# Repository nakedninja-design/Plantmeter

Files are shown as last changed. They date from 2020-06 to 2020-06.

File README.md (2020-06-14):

# Plant-Meter
Wireless Plant Meter (ESP8266 + ATTiny85)

The Plantmeter is a device that monitors the soil moisture levels of your plants.
It uses authenticated HTTP POST command over Wifi to communicate with a plantmeter hub that gathers all the data and notifies you when a plant needs watering.

Works with any webserver, home automation system  or other device that can process HTTP POST commands.

Works right out of the box in combination with our plantmeter hub.
Has its own webinterface to configure the ID, network settings and sleep time.

The plantmeter is a rechargeable, battery powered, device that can operate for 6 months on 1 charge.
Comes with STL design files for 3d printed enclosure.

You can buy the plantmeter on my website http://nakedninja.cc

Specifications:

Microcontroller: ESP8266 (ESP12)
- Flash Memory: 4MB
- RAM: 36kB
- Clock Speed: 80MHz
- Operating Voltage: 3.3V
Microcontroller: ATtiny85
- Flash Memory: 8kB
- RAM: 512B
- Clock Speed: 1MHz
- Operating Voltage: 2.7 to 5.5V
Power Supply Voltage: 5 Volt
Operating Current:
- Standby mode: 16~ 25uA
- Active mode: 50 ~ 80mA
Battery: Li-ion 3.7 Volt
Battery Connector: Solder Pads
Charger Module: TP4056

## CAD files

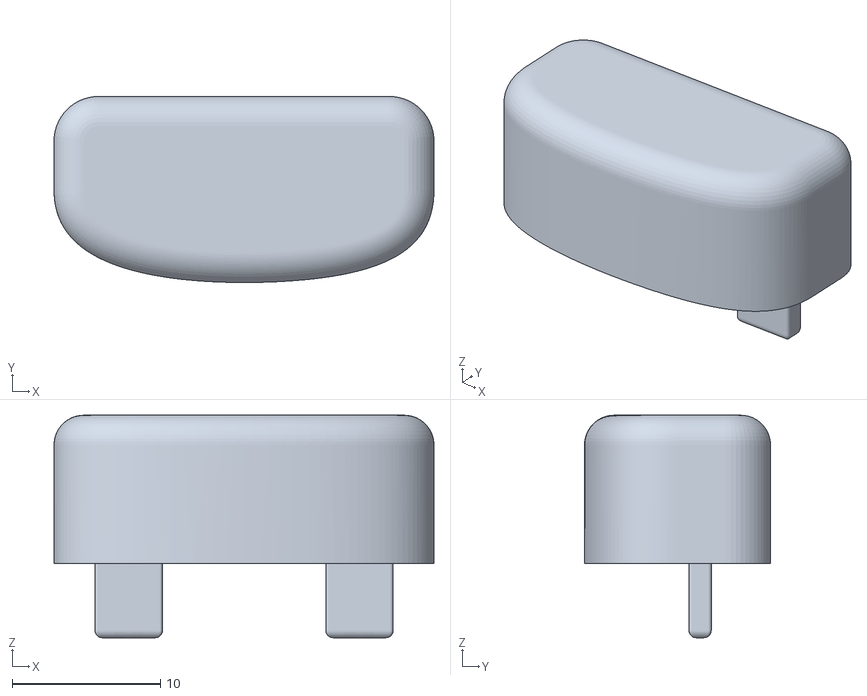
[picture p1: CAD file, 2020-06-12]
STL files Shorty/Shorty Enclosure Top.stl
25.6 x 12.5 x 15.0

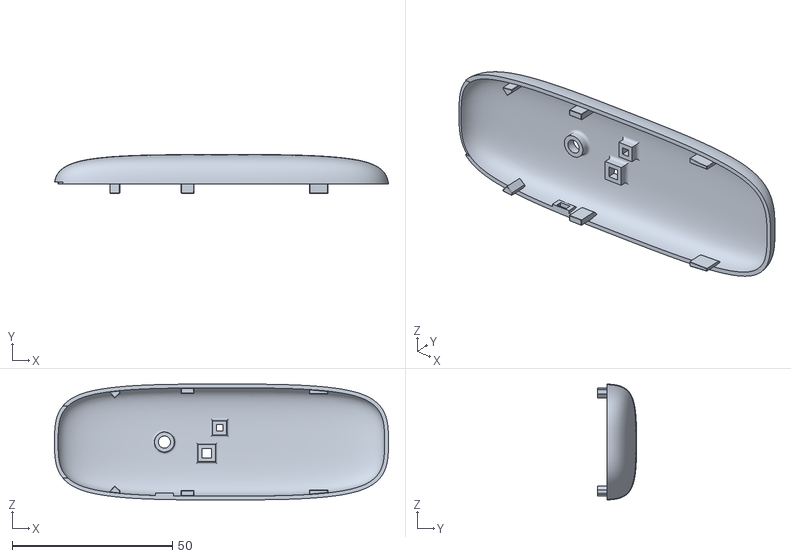
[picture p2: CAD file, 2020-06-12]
STL files TallBoy/TallBoy Enclosure Top.stl
104.2 x 12.2 x 36.2

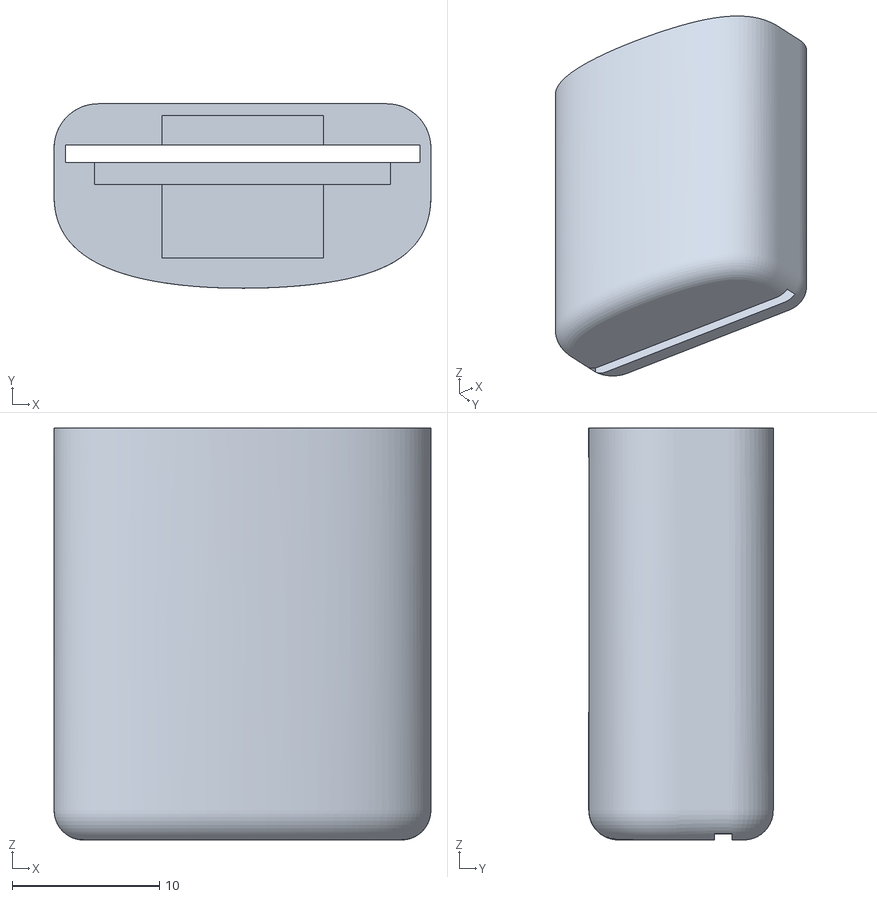
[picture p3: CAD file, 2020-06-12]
STL files Shorty/Shorty Enclosure Bottom.stl
25.6 x 12.5 x 28.0

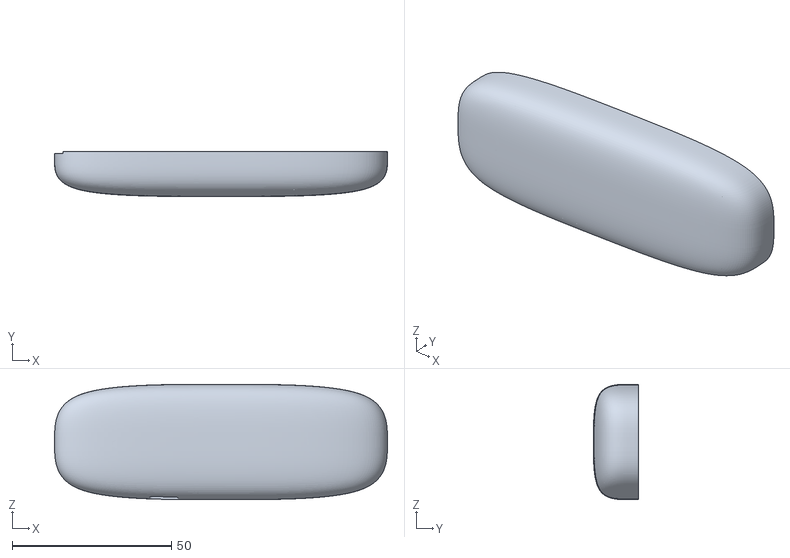
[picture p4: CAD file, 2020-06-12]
STL files TallBoy/TallBoy Enclosure Bottom.stl
104.4 x 14.2 x 36.2

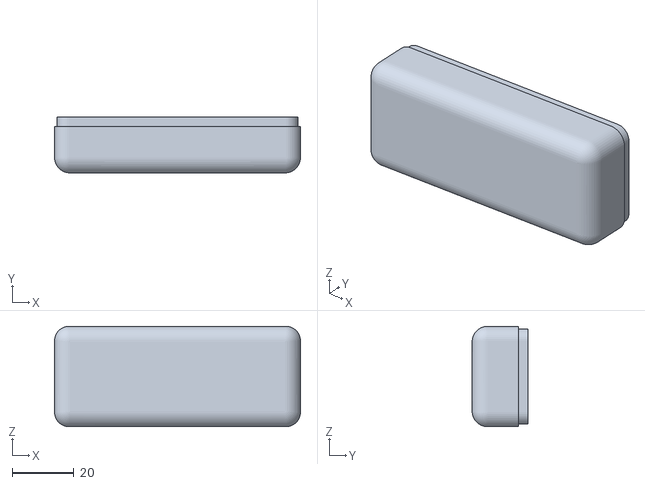
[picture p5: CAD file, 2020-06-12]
STL files Shorty/Plantmeter Enclosure Bottom.stl
79.4 x 18.0 x 32.4

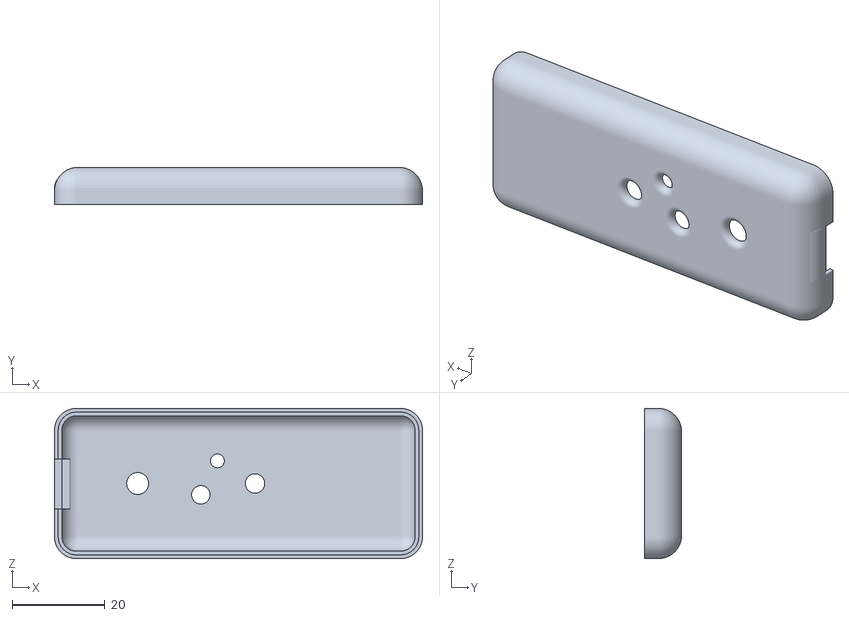
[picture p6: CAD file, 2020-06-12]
STL files Shorty/Plantmeter Enclosure Top.stl
79.4 x 8.00 x 32.4

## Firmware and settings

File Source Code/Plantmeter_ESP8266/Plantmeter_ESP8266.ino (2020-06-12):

/*
 * Web Interfacing Program for Plantmeter ESP
 * 
 * Company:    Naked Ninja (c) 2020
 * Website:    https://nakedninja.cc
 * Author(s):  Caner Erdem & Harm Verbeek
 * 
 * Pins that are connected on the PCB are:
 * GPIO4    -(I/O)->  SDA for I2C connection to the HTU21 & gy-49.
 * GPIO5    -(I/O)->  SCL for I2C connection to the HTU21 & gy-49.
 * GPIO12   -(TX)->   Serial communication with the ATtiny85
 * GPIO13   -(RX)->   Serial communication with the ATtiny85
 * GPIO14   -(O)->    RGB LED
 * ADC      -(I)->    Moisture sensor data input
 * 
 * Arduino IDE version 1.8.9
 * 
 * ESP8266 upload settings:
 *  Board:              Generic ESP8266 module
 *  Upload speed:       921600
 *  CPU freqyency:      80 MHz
 *  Flash frequency:    40 MHz
 *  Flash mode:         DOUT (compatible)
 *  Flash size:         4M (FS:1M)
 *  Crystal frequency:  26MHz
 *  Reset method:       nodemcu
 *  Debug port:         Disabled
 *  Debug level:        None
 *  IwIP variant:       v2 Lower Memory
 *  VTables:            Flash
 *  Exceptions:         Disabled
 *  Builtin LED:        2
 *  Erase flash:        All flash contents
 *  Espressif FW:       nonos-sdk 2.2.1 (legacy)
 *  SSL support:        All SSL ciphers (most compatible)
 * 
 * Programmer: AVRISP mkII
 * 
 * Component datasheets & usefull links:
 *  - GY-49: https://www.digchip.com/datasheets/parts/datasheet/280/MAX44009-pdf.php
 *  - HTU21: http://www.farnell.com/datasheets/1780639.pdf
 *  - Cap. Moisture sensor: https://wiki.dfrobot.com/Capacitive_Soil_Moisture_Sensor_SKU_SEN0193
 * 
 */

// Libraries
#include <ArduinoJson.h>
#include <FS.h>
#include <Wire.h>
#include "SparkFunHTU21D.h"
#include <ESP8266WiFi.h>          // https://github.com/esp8266/Arduino
#include <ESP8266WebServer.h>
#include <WiFiManager.h>          // https://github.com/tzapu/WiFiManager
#include <ESP8266HTTPClient.h>
#include <SoftwareSerial.h>
#include <Adafruit_NeoPixel.h>
#include <Ticker.h>

// Create timer
Ticker ticker;

// Code version
#define VERSION     "v1.27"

// Enable / Disable serial debug output
#define DEBUG true // flag to turn on/off debugging
#define USE_SERIAL if(DEBUG)Serial 

// Pin configuration
#define RGB_LED_PIN     14  // Connected RGB LED

// RGB settings & control modes
#define RGB_BRIGHTNESS    64          // Between 0 and 255
#define BLINK_DELAY       250         // Time in ms
#define LED_OFF           0,0,0       // OFF
#define LED_RED           255,0,0     // Red
#define LED_GREEN         0,255,0     // Green
#define LED_BLUE          0,0,255     // Blue
#define LED_YELLOW        255,255,0   // Yellow
#define LED_PURPLE        128,0,255   // Purple
#define LED_ORANGE        255,128,0   // Orange
#define LED_PINK          255,0,255   // Pink
#define LED_WHITE         255,255,255 // White

/* RGB LED status messages
 *    <COLOR>, <NUMBER>
 * <COLOR> is the color that will be visualized on the RGB LED
 * <NUMBER> is the amount of times the RGB will blink the given color
 * If <NUMBER> is set to -1, it will toggle the RGB LED to the given color
*/
#define BLINK_SAVE_CONFIG_SUCCESS       LED_GREEN, 2
#define BLINK_SAVE_CONFIG_ERROR         LED_RED, 2
#define BLINK_HTTP_RCV_OK               LED_GREEN, 2
#define BLINK_HTTP_RCV_ERROR            LED_RED, 2
#define BLINK_SSID_MISSING              LED_RED, 2
#define BLINK_WIFI_MAX_RETRIES          LED_RED, 2
#define TOGGLE_PORTAL                   LED_YELLOW, -1
#define TOGGLE_MOISTURE_MEASURE         LED_WHITE, -1
#define BLINK_MOISTURE_MEASURE_TIMEOUT  LED_RED, 2
#define BLINK_MOISTURE_MEASURE_FAIL     LED_RED, 2
#define BLINK_MODE_ERROR                LED_RED, 2
#define BLINK_SERIAL_NO_RESPONSE        LED_RED, 2
#define BLINK_MODE_CHARGE               LED_PURPLE, 5

// Modes
#define MODE_PORTAL             0x01 
#define MODE_SET_MOISTURE       0x02 
#define MODE_TEST               0x03 
#define WATCHDOG_TIMER          0x04
#define MODE_START_UP           0x05 
#define MODE_CHARGE             0x06
#define MODE_PRESSED            0x07
#define MODE_ERROR              0x99

// Serial communication codes
#define COMMUNICATION_ID_1      0xAA  // Header code 1 
#define COMMUNICATION_ID_2      0x55  // Header code 2
#define ESP_DONE                0xB1  // HEX code for shutdown command
#define REQUEST_MODE            0xA1  // HEX code for start up mode request
#define REQUEST_RESET           0xA2  // HEX code for ATtiny85 reset request
#define RCVD_ERROR              0xAF  // HEX code for Error message
#define RCVD_SUCCESS            0xFE  // HEX code for success message

// Delays, timers & retries
#define SERIAL_TIMEOUT          3000  // Max serial communication time per attempt
#define MOISTURE_TIMEOUT        20000 // Max time to put device in soil and press the function button
#define SERIAL_ATTEMPTS         5     // Amount of serial communication attempts before timeout
#define MAX_WIFI_RETRIES        12    // Amount of Wifi communication attempts before timeout
#define CMP_OFFSET              50    // Value for dry and wet offset check

// Default values
#define DEF_URL                 "http://%s.local/plantmeter"  // $s will be replaced with ssid
#define DEF_ID                  "Plantmeter"                  // Device ID
#define DEF_AUTH_USER           "user"                        // Basic Authentication User
#define DEF_AUTH_PASSWORD       "user"                        // Basic Authentication Password
#define DEF_SOIL_MOISTURE_DRY   600                           // Default dry level
#define DEF_SOIL_MOISTURE_WET   "250"                         // Default wet level
#define DEF_WAKE_TIME           300                           // Seconds the ATtiny85 will be awake if no ESP_DONE is received
#define DEF_SLEEP_TIME          "600"                         // Seconds the ATtiny85 will sleep

// Sensor settings
#define GY49_ADDR 0x4A  // Light sensor addres
HTU21D HTU21;           // HTU21 object creation

// Create softwareserial connection
SoftwareSerial mySerial(13, 12);  // RX, TX

// Create RGB LED class
Adafruit_NeoPixel pixel(1, RGB_LED_PIN, NEO_GRB + NEO_KHZ800);

// Allocate a JsonDocument
StaticJsonDocument<200> json;

// Global value's
char my_id[50]                = "";
char my_auth_password[10]     = "";
char my_soil_moisture_wet[10] = "";
char my_sleep_time[10]        = "";

// flags 
bool shouldSaveConfig = false;
bool flag_color_toggle = false;

// Mode
byte mode_state = 0;

// Call for timer interrupt
void tick() {
  controlRGB(TOGGLE_PORTAL);
}

//callback notifying us of the need to save config
void saveConfigCallback () {
  USE_SERIAL.println("Should save config");
  shouldSaveConfig = true;
}

void loadConfig () { 
    if (SPIFFS.begin()) {
      USE_SERIAL.println("Mounted file system");    
      File configFile = SPIFFS.open("/config.json", "r");
      
      if (configFile) {
        USE_SERIAL.println("Reading config file");
        // Deserialize the JSON document
        DeserializationError error = deserializeJson(json, configFile);
        if (error) {
          USE_SERIAL.println("Failed to load json config");
        } 
        else {    
          USE_SERIAL.println("\nparsed json");

          strcpy(my_id, json["id"]);
          strcpy(my_auth_password, json["auth_password"]);
          strcpy(my_soil_moisture_wet, json["soil_moisture_wet"]);
          strcpy(my_sleep_time, json["sleep_time"]);

          USE_SERIAL.println(my_id);
          USE_SERIAL.println(my_auth_password);
          USE_SERIAL.println(my_soil_moisture_wet);
          USE_SERIAL.println(my_sleep_time);
        }
        
        configFile.close();
      }
      else { // No config file found
        // create config file with default values
        USE_SERIAL.println("Creating config file with default values");
    
        strcpy(my_id, DEF_ID);
        strcpy(my_auth_password, DEF_AUTH_PASSWORD);
        strcpy(my_soil_moisture_wet, DEF_SOIL_MOISTURE_WET);
        strcpy(my_sleep_time, DEF_SLEEP_TIME);

        USE_SERIAL.println("Saving config");

        json["id"] = my_id;
        json["auth_password"] = my_auth_password;
        json["soil_moisture_wet"] = my_soil_moisture_wet;
        json["sleep_time"] = my_sleep_time;
    
        File configFile = SPIFFS.open("/config.json", "w+");
        if (!configFile) {
          USE_SERIAL.println("Failed to open config file for writing");
        } 
        else {
          // Serialize JSON to file
          if (serializeJson(json, configFile) == 0) {
            USE_SERIAL.println(F("Failed to write to file"));
           } else {
            USE_SERIAL.println(F("Succeeded to write to file"));
          }
        
          // Close the file
          configFile.close();
        }
   }
   
  } 
  else {
    USE_SERIAL.println("Failed to mount FS");
  } 
} 

void saveConfig () { 
   if (SPIFFS.begin()) {
      USE_SERIAL.println("Mounted file system");    
      // If you get here you have connected to the WiFi
      USE_SERIAL.println("Connected and saving configuration ...");

      json["id"] = my_id;
      json["auth_password"] = my_auth_password;
      json["soil_moisture_wet"] = my_soil_moisture_wet;
      json["sleep_time"] = my_sleep_time;

      File configFile = SPIFFS.open("/config.json", "w+");
      if (!configFile) {
        USE_SERIAL.println("Failed to open config file for writing");
      } 
      else {
        // Serialize JSON to file
        if (serializeJson(json, configFile) == 0) {
          USE_SERIAL.println(F("Failed to write to file"));
          controlRGB(BLINK_SAVE_CONFIG_ERROR);
        } 
        else {
          USE_SERIAL.println(F("Succeeded to write to file"));
          controlRGB(BLINK_SAVE_CONFIG_SUCCESS);
        }
      
        // Close the file
        configFile.close();
      }
    } 
    else {
      USE_SERIAL.println("Failed to mount FS");
    } 
} 

float readLuminance () {
  unsigned int data[2];
  Wire.beginTransmission(GY49_ADDR);
  Wire.write(0x03);
  Wire.endTransmission();
  
  Wire.requestFrom(GY49_ADDR, 2);  // Request 2 bytes of data
  if (Wire.available() == 2) {     // Read 2 bytes of data luminance msb, luminance lsb
    data[0] = Wire.read();         // Lux High-Byte Register 0x03
    data[1] = Wire.read();         // Lux Low-Byte Register 0x04
  }
  
  // Convert the data to lux
  int exponent = (data[0] & 0xF0) >> 4;                       // Exponent = 8xE3 + 4xE2 + 2xE1 + E0
  int mantissa = ((data[0] & 0x0F) << 4) | (data[1] & 0x0F);  // Mantissa = Mantissa = 128xM7 + 64xM6 + 32xM5 + 16xM4 + 8xM3 + 4xM2 + 2xM1 + M0
  float luminance = pow(2, exponent) * mantissa * 0.045;      // Lux = 2(exponent) x mantissa x 0.045

  return luminance;
}

float readSoilMoisture () {
  float total = 0;
  float temp_one = 0;
  
  for (int y = 0; y < 2; y++) {
    temp_one = system_adc_read(); 
    delay(10);
  }
  
  for (int x = 0; x < 10; x++) {
    temp_one = system_adc_read();
//    USE_SERIAL.println(tempp);
    total += temp_one;
    delay(10);
  }
  
  float average = total / 10;
  return average;
}

void controlRGB (int r, int g, int b, int blink) {
  if (blink == -1) {
      if (flag_color_toggle == false) {
        pixel.setPixelColor(0, pixel.Color(LED_OFF)); 
        pixel.show(); 
        flag_color_toggle = true;
      } else {
        pixel.setPixelColor(0, pixel.Color(r,g,b)); 
        pixel.show();
        flag_color_toggle = false;
      }        
  }
  else {
    for (int i = 0; i < blink; i++) {
      pixel.setPixelColor(0, pixel.Color(r,g,b)); 
      pixel.show(); // This sends the updated color to the hardware.
      delay(BLINK_DELAY);
      pixel.setPixelColor(0, pixel.Color(LED_OFF)); // switch led off.
      pixel.show();
      delay(BLINK_DELAY);
    }  
  }
}

void serialSend (byte mode, byte dbyte1,byte dbyte2=0,byte dbyte3=0,byte dbyte4=0) {
  delay(10); mySerial.write(COMMUNICATION_ID_1);
  delay(10); mySerial.write(COMMUNICATION_ID_2);
  
  if (mode == MODE_START_UP) {
   delay(10); mySerial.write(mode);
   delay(10); mySerial.write(dbyte1);
   delay(10); mySerial.write(dbyte2);
   delay(10); mySerial.write(dbyte3);
   delay(10); mySerial.write(dbyte4);      
  }
  else {
    delay(10); mySerial.write(dbyte1);
  }
}

bool serialCheck(byte mode){
  byte incoming_byte = 0;
  byte message_status = 0;
  
  if (mySerial.available() > 0) {
    long int timer_one = millis();
    while (millis() < (timer_one + SERIAL_TIMEOUT)) {
      incoming_byte = mySerial.read();
      //USE_SERIAL.print("  Received: ");
      //USE_SERIAL.println(incoming_byte, HEX);
      if (incoming_byte == COMMUNICATION_ID_1 && message_status == 0) {
        message_status = 1; 
      }
      else if (incoming_byte == COMMUNICATION_ID_2 && message_status == 1)  {
        message_status = 2; 
      } 
      else if (incoming_byte == mode && message_status == 2)  {
        USE_SERIAL.println("serialCheck ok for mode");
        return true;         
      }      
      else {
        return false;
      }
    }
  }
  
  return false;
}

byte serialMessage (byte mode, byte dbyte1,byte dbyte2=0,byte dbyte3=0,byte dbyte4=0) {
  USE_SERIAL.println("Requesting data");
  byte incoming_byte = 0;
  byte message_status = 0;
  long int timer_one = millis();
  bool check_one = true;
  int count_one = 0;
  byte res;
  
  while (check_one) {
    serialSend(mode, dbyte1,dbyte2,dbyte3,dbyte4);
    count_one++;
   
    while (millis() < (timer_one + SERIAL_TIMEOUT)) {
      if (mySerial.available() > 0) {
        incoming_byte = mySerial.read();
        USE_SERIAL.print("  Received: ");
        USE_SERIAL.println(incoming_byte, HEX);
        if (incoming_byte == COMMUNICATION_ID_1 && message_status == 0) {
          message_status = 1; 
        } 
        else if (incoming_byte == COMMUNICATION_ID_2 && message_status == 1)  {
          message_status = 2; 
          break;
        } 
        else if (message_status == 2) {
          USE_SERIAL.println("  MSG status 2, reading data");

          switch (incoming_byte) {
            case MODE_START_UP: 
              USE_SERIAL.println("  MODE_START_UP");
              return MODE_START_UP;
            case MODE_PORTAL:       
              USE_SERIAL.println("  MODE_PORTAL");
              return MODE_PORTAL;
            case MODE_TEST: 
              USE_SERIAL.println("  MODE_TEST");
              return MODE_TEST;
            case MODE_SET_MOISTURE:
              USE_SERIAL.println("  MODE_SET_MOISTURE");
              return MODE_SET_MOISTURE;
            case WATCHDOG_TIMER: 
              USE_SERIAL.println("  WATCHDOG_TIMER ");
              return WATCHDOG_TIMER;
            case RCVD_SUCCESS:
              USE_SERIAL.println("Received OK"); 
              return RCVD_SUCCESS;
            case RCVD_ERROR:
              USE_SERIAL.println("Received ERROR"); 
              return RCVD_ERROR;
            case MODE_CHARGE:
              USE_SERIAL.println("  MODE_CHARGE");
              return MODE_CHARGE;
            case MODE_ERROR:
              USE_SERIAL.println("  MODE_ERROR");
              return MODE_ERROR;
            default:
              USE_SERIAL.println("  No match in serial communication"); 
              message_status = 0; 
              break;          
          } 
        }
        else {
          message_status = 0; 
        }
      }
    }
      

    if (count_one >= SERIAL_ATTEMPTS) {
      USE_SERIAL.println("  Failed to get response");
      check_one = false;
    }
  }
  
  // Only comes here if no serial response was received
  controlRGB(BLINK_SERIAL_NO_RESPONSE);
  shutdownESP();
}

void shutdownESP () {
  USE_SERIAL.println("\nSignal the ATtiny to turn off the voltage regulator...");

  serialSend(0, ESP_DONE); // we are done, shutdown
  serialSend(0, ESP_DONE); // we are done, shutdown
  serialSend(0, ESP_DONE); // we are done, shutdown
  delay(200);  
  controlRGB(LED_OFF, 0);  // turn off the activity led
  ESP.deepSleep(0);
  yield();
}
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
void loop () {
   yield();
}

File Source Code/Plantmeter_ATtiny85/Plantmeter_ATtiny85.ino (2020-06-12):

 /*
 * Sleep Program for Plantmeter ATtiny85
 * 
 * Company:    Naked Ninja (c) 2020
 * Website:    https://nakedninja.cc
 * Author(s):  Caner Erdem & Harm Verbeek
 * 
 * Pin configuration:
 *                                   +-\/-+ 
 *        PCINT5/RESET/ADC0/dW/PB5  1|    |8  Vcc 
 * PCINT3/XTAL1/CLKI/OC1B/ADC3/PB3  2|    |7  PB2/SCK/USCK/SCL/ADC1/T0/INT0/PCINT2
 * PCINT4/XTAL2/CLKO/OC1B/ADC2/PB4  3|    |6  PB1/MISO/DO/AIN1/OC0B/OC1A/PCINT1
 *                             GND  4|    |5  PB0/MOSI/DI/SDA/AIN0/OC0A/OC1A/AREF/PCINT0
 *                                   +----+
 * PB0  -(I)->  Wake up switch
 * PB1  -(Tx)-> Serial communication with ESP8266
 * PB2  -(O)->  Enable pin of voltage regulator
 * PB3  -(I)->  Wake up switch 2
 * PB4  -(RX)-> Serial communication with ESP8266
 * PB5  -(x)->  N/C
 * 
 * ATtiny85 upload settings:
 * (In order to program the ATtint85 an Arduino UNO with the ArduinoISP code is required.)
 *  Board:      Attiny25/45/85
 *  Processor:  Attiny85
 *  Clock:      Internal 1MHz
 *  Programmer: Arduino as ISP 
 *
 */

//Library's
#include <avr/sleep.h>      // Sleep Modes
#include <avr/power.h>      // Power management
#include <avr/wdt.h>        // Watchdog timer
#include <SoftwareSerial.h> // Serial communication

// Pin configuration
#define BUTTON_FRONT      0
#define BUTTON_SIDE       3
#define VREG_ENABLE       2

// Modes
#define MODE_PORTAL             0x01
#define MODE_SET_MOISTURE       0x02
#define MODE_TEST               0x03
#define WATCHDOG_TIMER          0x04
#define MODE_START_UP           0x05
#define MODE_CHARGE             0x06
#define MODE_PRESSED            0x07
#define MODE_ERROR              0x99

// Serial communication codes
#define COMMUNICATION_ID_1      0xAA
#define COMMUNICATION_ID_2      0x55
#define ESP_DONE                0xB1
#define REQUEST_MODE            0xA1
#define REQUEST_RESET           0xA2
#define RCVD_ERROR              0xAF
#define RCVD_SUCCESS            0xFE

// Delays & timers
#define CHARGE_DELAY            5000
#define SET_MOISTURE_DELAY      1000 
#define SERIAL_TIME_OUT         5000
#define ESP_BLINK_DELAY         6000

// Default value's
#define WAKE_TIME               300 // Default value (300/60 = 5min)  
#define SLEEP_MULTIPLIER        75  // Default value (75*8 = 10min)

// Object creations
SoftwareSerial mySerial(4, 1);  // (RX, TX)

// Timer variables
unsigned long timer_one;  // Timer of main program
unsigned long timer_two;  // Timer for getSettings();
unsigned long timer_three;// Timer for function button detection
unsigned long timer_four; // Timer for function button detection
int wake_time;            // Maximum time the ATtiny85 is awake
int sleep_multiplier;     // Multiplier for ATtiny85 sleep duration (8s*sleep_multiplier)
int wdt_sleep_counter;    // Watchdog sleep counter

boolean goto_sleep = true;
boolean flag_wdt = false;
boolean flag_moisture = false;
byte mode;
byte incoming_byte = 0;
byte message_status = 0;

ISR (WDT_vect) {
  //  wdt_disable();    // Disable watchdog
  flag_wdt = true; 
}

void reboot () {
  cli();
  WDTCR = 0xD8 | WDTO_60MS;
  sei(); 
  /*Options
    WDTO_15MS, WDTO_30MS, WDTO_60MS, WDTO_120MS, WDTO_250MS,
    WDTO_500MS, WDTO_1S, WDTO_2S, WDTO_4S, WDTO_8S
  */
  wdt_reset();
  while (true) {}
}

void resetWatchdog () {
  MCUSR = 0;                                    // Clear various "reset" flags
  WDTCR = bit (WDCE) | bit (WDE) | bit (WDIF);  // Allow changes, disable reset, clear existing interrupt
  WDTCR = bit (WDIE) | bit (WDP3) | bit (WDP0); // Set WDIE, and 8 seconds delay
  wdt_reset();                                  // Reset

  //Other delay settings:
  //  WDTCR = bit (WDIE) | bit (WDP2) | bit (WDP1);             // Set WDIE, and 1 seconds delay
  //  WDTCR = bit (WDIE) | bit (WDP2) | bit (WDP1)| bit (WDP0); // Set WDIE, and 2 seconds delay
  //  WDTCR = bit (WDIE) | bit (WDP3);                          // Set WDIE, and 4 seconds delay
  //  WDTCR = bit (WDIE) | bit (WDP3) | bit (WDP0);             // Set WDIE, and 8 seconds delay 
}

void chargeSleep () {
  mySerial.end();
  delay(ESP_BLINK_DELAY);
  digitalWrite(VREG_ENABLE, LOW);   // disable voltage regulator
  
  set_sleep_mode (SLEEP_MODE_PWR_DOWN);
  ADCSRA = 0;             // turn off ADC
  power_all_disable ();   // power off ADC, Timer 0 and 1, serial interface
  wdt_disable ();         // Disable watchdog incase it wasn't disabled
  noInterrupts ();        // Timed sequence coming up
  sleep_enable ();        // Ready to sleep
  interrupts ();          // Interrupts are required now
  sleep_cpu ();           // Sleep     

  /*Returns here after wakeup !!!*/
  
  sleep_disable ();                 // Precaution
  power_all_enable ();              // Power everything back on
  mode = MODE_TEST;     // Function button short press
  digitalWrite (VREG_ENABLE, HIGH); // enable voltage regulator to power the connected MCU
  
  timer_one = millis();
  goto_sleep = false;   // Disable goto_sleep
  message_status = 0;   // Reset message status
  mySerial.begin(9600);
  mySerial.flush();
}
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
